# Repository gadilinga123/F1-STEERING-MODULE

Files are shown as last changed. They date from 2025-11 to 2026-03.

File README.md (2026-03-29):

# F1 Steering Wheel Control Module (Ferrari Challenge Project)

## Overview
Designed and implemented an embedded ECU for an F1-style steering wheel, developed under requirements defined by the Ferrari engineering team.  
The system integrates real-time driver inputs, CAN communication, and display feedback.

Complete hardware design files, schematics, and demonstration are included in this repository.

---

## Demo
👉 Full system demonstration (inputs, CAN, display output):  
[▶ Watch Demo Video](./demo.mp4)

---

## System Architecture


The system is built around a centralized control architecture:
- **MCU:** STM32F103 (ARM Cortex-M3)
- **Communication:** CAN (vehicle interface), UART (debug)
- **Display:** SPI-based TFT LCD
- **Inputs:** Digital switches + analog signals (clutch, rotary)
- **Power:** 12V automotive input + USB fallback

---

## My Contributions
- Led end-to-end system development from requirements to validation
- Defined system architecture and hardware partitioning
- Designed complete schematic and 4-layer PCB (Altium Designer)
- Implemented power architecture (DC-DC + LDO design trade-offs)
- Performed hardware bring-up, debugging, and validation using lab equipment
- Resolved critical hardware issue (boot failure due to reset circuit)

---

## System Features
- Multi-input acquisition:
  - Digital inputs (Gear Up/Down + configurable buttons)
  - Analog inputs (clutch control and rotary selector)
- CAN bus communication:
  - Reception of vehicle data (e.g., temperature signals)
  - Control of LED outputs
- Real-time user interface:
  - TFT display (320×240) with dynamic feedback
- Dual power architecture:
  - 12V automotive supply
  - USB-based supply for controlled debugging

---

## Hardware Design

### PCB Design
- 4-layer stackup: Signal / Ground / Power / Signal
- Controlled impedance routing for CAN and USB
- EMI-aware layout and signal integrity optimization

### Power Architecture
- 12V → 3.3V DC-DC converter (>90% efficiency, <5% ripple)
- LDO regulator for low-noise operation and USB debugging
- Protection features:
  - TVS diode (transient suppression)
  - Reverse polarity protection
  - Input filtering (EMI mitigation)

---

## Firmware
- Developed in C using STM32CubeIDE
- Modular architecture:
  - Input acquisition layer
  - Processing logic
  - Output control (display + LEDs)
- CAN communication handling and debugging
- SPI-based display integration

---

## Validation & Testing
- Hardware bring-up and debugging
- Power integrity verification
- Clock stability validation (external oscillator)
- Functional testing:
  - Inputs (buttons, analog)
  - CAN communication
  - Display output
- System-level validation against requirements

---

## Key Technical Metrics
- Power Conversion Efficiency: >90%
- Output Ripple: <5%
- PCB: 4-layer design
- Supply Inputs: 12V automotive + 5V USB fallback

---

## Challenges & Solutions
- **Thermal constraints (no active cooling):**
  - Used efficient DC-DC + thermal vias and ground planes

- **Manufacturing delays:**
  - Continued development using STM32 Nucleo + HMI module

- **Boot failure issue:**
  - Root cause: incorrect reset switch footprint
  - Fix: hardware rework and validation

- **Cost vs automotive protection:**
  - Replaced surge stopper IC with discrete protection (TVS + diode)

---

## Design Files
- Schematics: `/SCHEMATICS/`
- PCB Layout & Altium Files: root directory
- Gerber Files: `/GERBER/`
- Datasheets: `/DATASHEETS & AN/`

---

## Outcome
- Achieved full compliance with all functional requirements
- Recognized as the **only team project meeting all specifications**

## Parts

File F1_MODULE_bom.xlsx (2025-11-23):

Comment | Description | Designator | Footprint | LibRef | Quantity
CC0402KRX7R7BB104 | CAP CER 0.1UF 16V X7R 0402 | C1, C8, C9, C10, C11, C12, C15, C16, C17, C18, C19, C20 | FP-CC0402-MFG | CMP-03422-000048-1 | 12
TMK105B7104KVHF | 0.1 µF ±10% 25V Condensatori ceramici X7R 0402 (1005 metrico), None | C2, C3, C21, C23, C26 | FP-0402-L_1_0_0_05-W_0_5-MFG | CMP-14477-000162-2 | 5
CC0603KRX5R7BB475 | CAP CER 4.7UF 16V X5R 0603 | C4 | FP-CC0603-DA-MFG | CMP-03422-001236-1 | 1
0603CG300J500NT | C0603 30 pF X8R 30ppm/°C 1.00% 25 V | C5, C6 | FP-C0603C-CF-MFG | CMP-03020-002234-1 | 2
EMK212BB7106KG-T | CAP CER 10UF 16V X7R 0805 | C7, C13, C14 | FP-0805-L_2_0_0_2-W_1_25-MFG | CMP-14477-000192-1 | 3
TMK325B7226KMHP | CAP CER 22UF 25V X7R 1210 | C22, C24 | FP-1210-L_3_2_0_3-W_2_5_0-MFG | CMP-14477-002449-2 | 2
CL21C220JBANNNC | Cap Ceramic 22pF 16V C0G 10% 0805 T/R | C25 | CAP_0805 | CL21C220JBANNNC | 1
RVT1H2R2M0405 | Radial Can - SMD ALUMINUM ELECTROLYTIC CAPACITOR S 50V 2.2muF ±20% 0.157Dia 4.00mm | C31 | CAP_EEE_B_PAN | RVT1H2R2M0405 | 1
CC0805KKX7R9BB394 | CAP 390nF 50V ±10% 0805 (2012 Metric) Thickness 1.1mm SMD | C32 | CAPC0805(2012)110_N | CMP-1036-04624-1 | 1
C2012X7S1A156MT000E | Multilayer Ceramic Capacitors 15μF ±20% 25V X5R SMD 0805 | C33 | FP-C2012-125-0_2-MFG | CMP-08246-004727-1 | 1
150060VS75000 | WURTH ELEKTRONIK - 150060VS75000 - LED, Green, SMD, 0603, 30 mA, 2 V, 570 nm | D1 | WL-SMCW_0603_150060xx75000 | CMP-1426-00006-7 | 1
150080RS75000 | LED Uni-Color Red 630nm 2-Pin Chip 0805(2012Metric) T/R | D2 | WL-SMCW_0805_150080xx75000 | CMP-1426-00011-3 | 1
ESD5Z5.0T1G | Transient Voltage Suppressor, Micro-Packaged Diode for ESD Protection, 2-Pin SOD-523, Pb-Free, Tape and Reel | D3 | ONSC-SOD-523-2-502-01_V | CMP-1063-00102-1 | 1
SM712-02HTG | TVS DIODE 12V 31V SOT23-3 | D4 | FP-SM712-MFG | CMP-2000-07561-2 | 1
CMS06(TE12L,Q,M) | DIODE SCHOTTKY 30V 2A MFLAT | D5 | FP-M-FLAT-MFG | CMP-2000-06115-2 | 1
SMBJ17CA | DO-214AA SMB SMBJ Surface Mount 1 Zener Tvs Diode 18.9V 21.7A 600W -55C~150C TJ | D6 | SMBJSeries_LTF | SMBJ17CA | 1
MINISMDC110F/24-2 | PTC RESET FUSE 24V 1.1A 1812 | F1 | FP-MINISMDC110F-24-2-MFG | CMP-08606-000001-1 | 1
FTSH-103-01-F-DV-TR | CONN HEADER SMD 6POS 1.27MM | J1 | FP-FTSH-103-01-F-DV-TR-MFG | CMP-02766-001757-1 | 1
473460001 | CONN RCPT USB2.0 MICRO B SMD R/A | J2 | FP-473460001-MFG | CMP-2000-05246-2 | 1
HTSW-104-07-G-S | CONN HEADER VERT 4POS 2.54MM | J3 | FP-HTSW-104-07-G-S-MFG | CMP-02766-001776-1 | 1
22-28-4121 | KK 254 Breakaway Header, Vertical, 12 Circuits, Tin (Sn) Plating, Mating Pin Length 8.13mm | J4, J6 | 12 POS_2.54MM_MOLEX | 22-28-4121 | 2
1729144 | Block, Terminal; 13.5 A; 250 V; 5.08 mm; 26 to 16 AWG; 4; Screw; Solder; 4 kV | J5 | PHOENIX_1729144 | 1729144 | 1
61300311121 | CONN HEADER VERT 3POS 2.54MM | J7, J8, J9 | 61300311121 | CMP-1502-01062-3 | 3
MDMK2020T1R0MMV | Inductor Power Shielded Wirewound 1uH 20% 1MHz Metal 1.9A 0.064Ohm DCR Automotive T/R | L1 | IND_MDMK2020T1R0MM_TAY | MDMK2020T1R0MMV | 1
SWPA4020S8R2MT | General Purpose Inductor, 8.2uH, 20%, 1 Element, Ferrite-Core, SMD, 1212 | L2 | IND_SWPA4020S8R2MT | SWPA4020S8R2MT | 1
DFE201210U-R33M=P2 | FIXED IND .33UH 3.4A 31MOHM | L3 | FP-DFE201210U-MFG | CMP-06042-016608-1 | 1
SI1013R | MOSFET P-CH 20V 350MA SC75A | Q1 | FP-C15-1445-MFG | CMP-02550-000328-1 | 1
RC0402JR-0710KL | RES 10K OHM 5% 1/16W 0402 | R1, R4, R11, R15 | FP-RC0402-0_4-MFG | CMP-2002-07915-3 | 4
0402WGF1000TCE | RES SMD 1.2K OHM 1% 1/10W 0402 | R2, R3 | FP-MCS0402-MFG | CMP-02407-010762-1 | 2
ERJ2GE0R00X | Chip Resistor, 0 Ohm, 0.1 W, -55 to 155 degC, 0402 (1005 Metric), RoHS, Tape and Reel | R5, R6, R21, R22, R37 | RESC1005X40X25LL05T05 | CMP-2000-07451-1 | 5
AECR0402F20R0K9 | RES SMD 20 OHM 1% 1/16W 0402 | R7, R8, R10, R23 | FP-RT0402-MFG | CMP-2002-02569-2 | 4
CRCW0402390RFKED | RES Thick Film, 390Ω, 1%, 0.063W, 100ppm/°C, 0402 | R9 | FP-CRCW0402-e3-MFG | CMP-1011-00463-3 | 1
ERA2AEB152X | RES SMD 1.5K OHM 0.1% 1/16W 0402 | R12 | RESC1005X40X25LL10T10 | CMP-2002-05878-1 | 1
1206W4F120LT5E | 0.12Ω ±1% 0.25W 1206 Thick Film Chip Resistor AEC-Q200 compliant | R13 | FP-RMCF1206-MFG | CMP-26527-005834-1 | 1
TNPW040233K0BEED | RES SMD 33K OHM 0.1% 1/16W 0402 | R14 | FP-ERA2A-MFG | CMP-2002-05885-2 | 1
AC0402FR-0782KL | CRGCQ0402 82KΩ 1% ±100ppm/°C 50V | R16 | FP-CRGCQ0402-IPC_C | CMP-03211-009791-1 | 1
ERJ-2GEJ161X |  | R17 | RESC1005X40X25NL05T05 | CMP-2002-00462-1 | 1
RC0402JR-074K7L | 4.7 kOhms ±5% 0.063W, 1/16W Chip Resistor 0402 (1005 Metric) Moisture Resistant Thick Film | R18, R20 | FP-RC0402-0_4-MFG | CMP-2002-08011-2 | 2
RC0402FR-07100KL | 100 kOhms ±1% 0.063W, 1/16W Chip Resistor 0402 (1005 Metric) Moisture Resistant Thick Film | R24, R26 | RESC1005X40X25NL05T10 | CMP-2002-07343-1 | 2
AF0402JR-0720KL | Anti-Sulfurated Chip Resistors Automotive Grade 20kΩ 5% 100ppm/°C 0402 | R25 | FP-AF0402-MFG | CMP-03412-045777-1 | 1
0402WGF4022TCE | Anti-Sulfurated Chip Resistors Automotive Grade 40.2kΩ 1% 100ppm/°C 0402 | R27 | FP-AF0402-MFG | CMP-03412-045117-1 | 1
ARG03BTC6341 | RES SMD 100 OHM 1% 1/8W 0603 | R28 | FP-MCT0603-MFG | CMP-02407-002952-1 | 1
CRM2512-JW-3R3ELF | Res Thick Film 2512 3.3 Ohm 5% 2W ±200ppm/C Pad SMD T/R | R38 | RESC6331X80N | CRM2512-JW-3R3ELF | 1
1977223-4 | SWITCH TACTILE SPST-NO 0.05A 12V | SW6 | FP-1977223-4-MFG | CMP-03407-000020-1 | 1
STM32F103CBT6TR | ARM® Cortex®-M3 STM32F1 Microcontroller IC 32-Bit 72MHz 128KB (128K x 8) FLASH | U1 | FP-LQFP48-5B-MFG | CMP-0237-00247-4 | 1
MP2313GJ-P | Switching Voltage Regulators High Effic 1A,24V, 2MHz Syn StepDw Conv | U2 | TSOT23-8_MP2313_MNP | MP2313GJ-P | 1
SN65HVD232QDRQ1 | Texas Instruments - SN65HVD232QDRQ1 - Can Bus, Transceiver, Can, 1, 1, 3 V, 3.6 V, SOIC | U3 | CAN IC | SN65HVD232QDRQ1 | 1
TL1963A-33DCYR | Single Output Low Noise LDO, 1.5 A, Fixed 3.3 V Output, 2.1 to 20 V Input, 4-pin SOT-223 (DCY), -40 to 125 degC, Green (RoHS & no Sb/Br) | U4 | DCY0004A_N | CMP-0395-00535-2 | 1
ABM3BAIG-8.000MHZ-1Z-T | CRYSTAL 8.0000MHZ 18PF SMD | Y1 | FP-ABM3BAIG-MFG | CMP-27762-004085-1 | 1

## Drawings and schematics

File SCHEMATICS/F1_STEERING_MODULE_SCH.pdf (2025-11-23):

# F1 STEERING MODULE

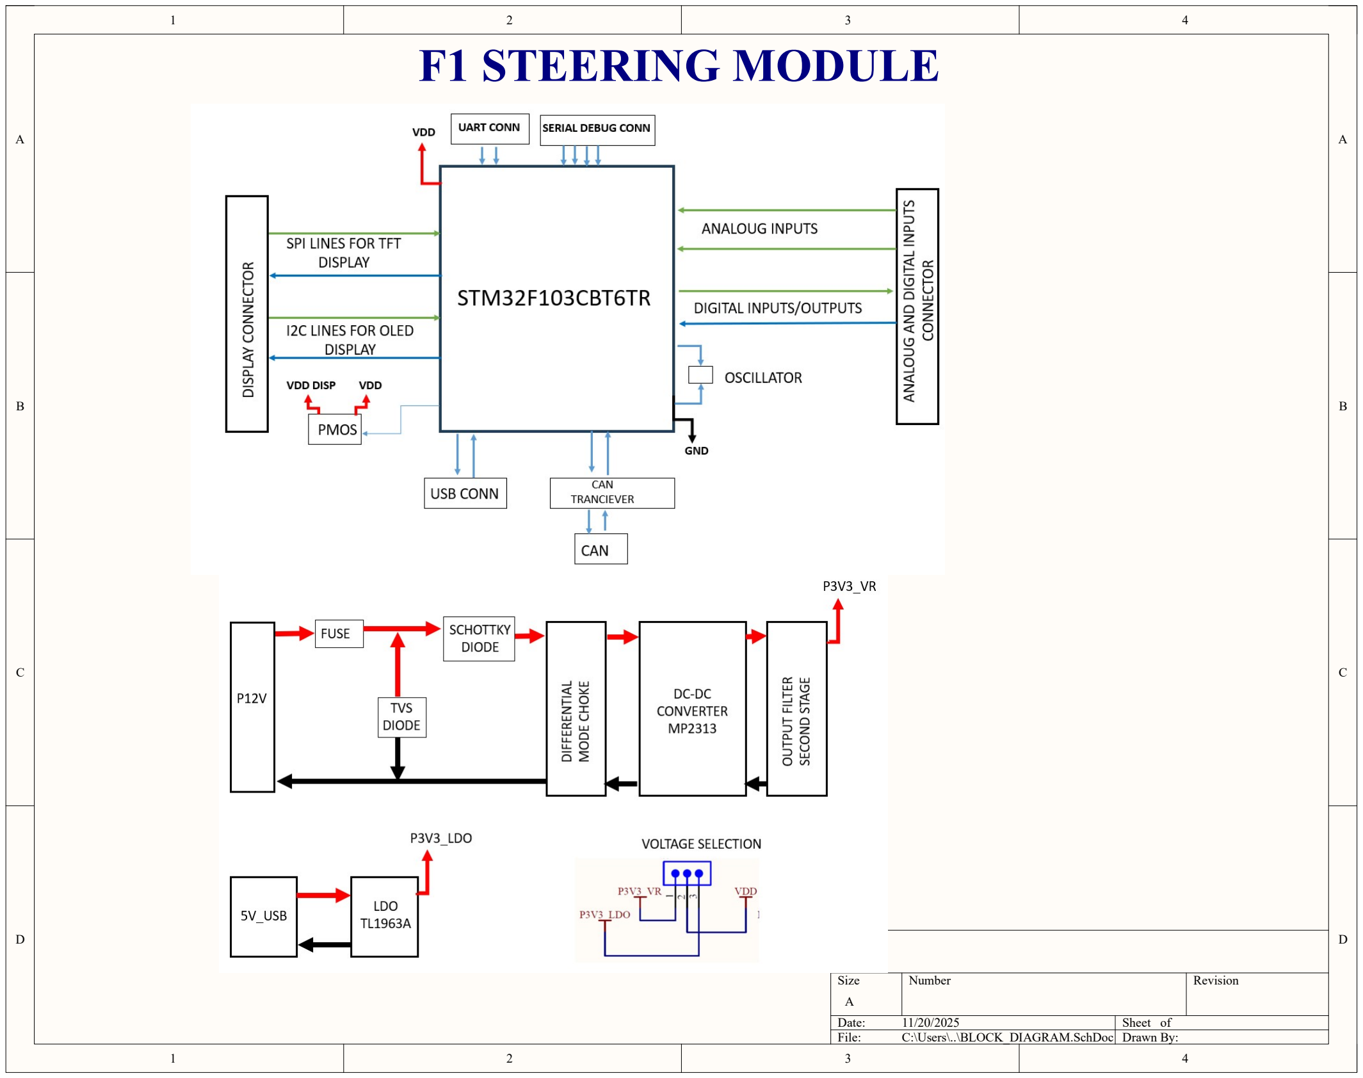
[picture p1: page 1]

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
Title

Size | Number | Revision
A
Date: | 11/20/2025 | Sheet of
File: | C:\Users\..\BLOCK_DIAGRAM.SchDoc | Drawn By:

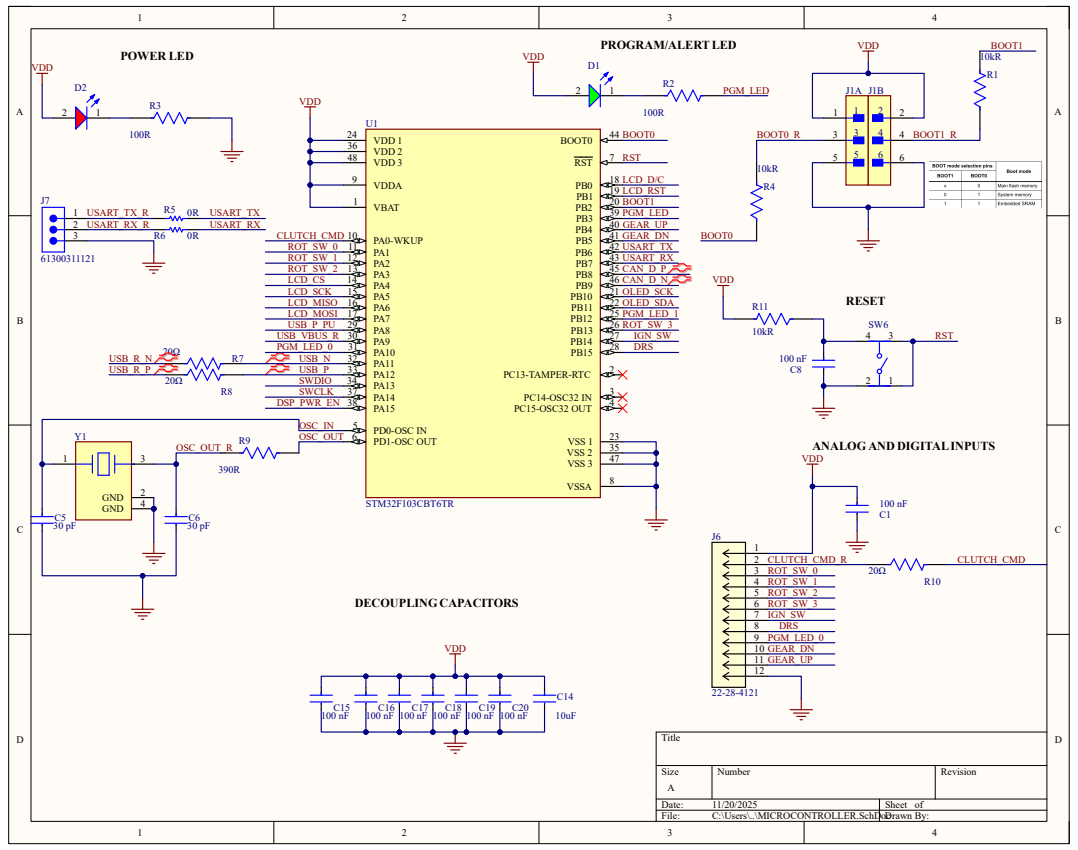
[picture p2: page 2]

ANALOG AND DIGITAL INPUTS
VDD

# 5V_USB 1 2

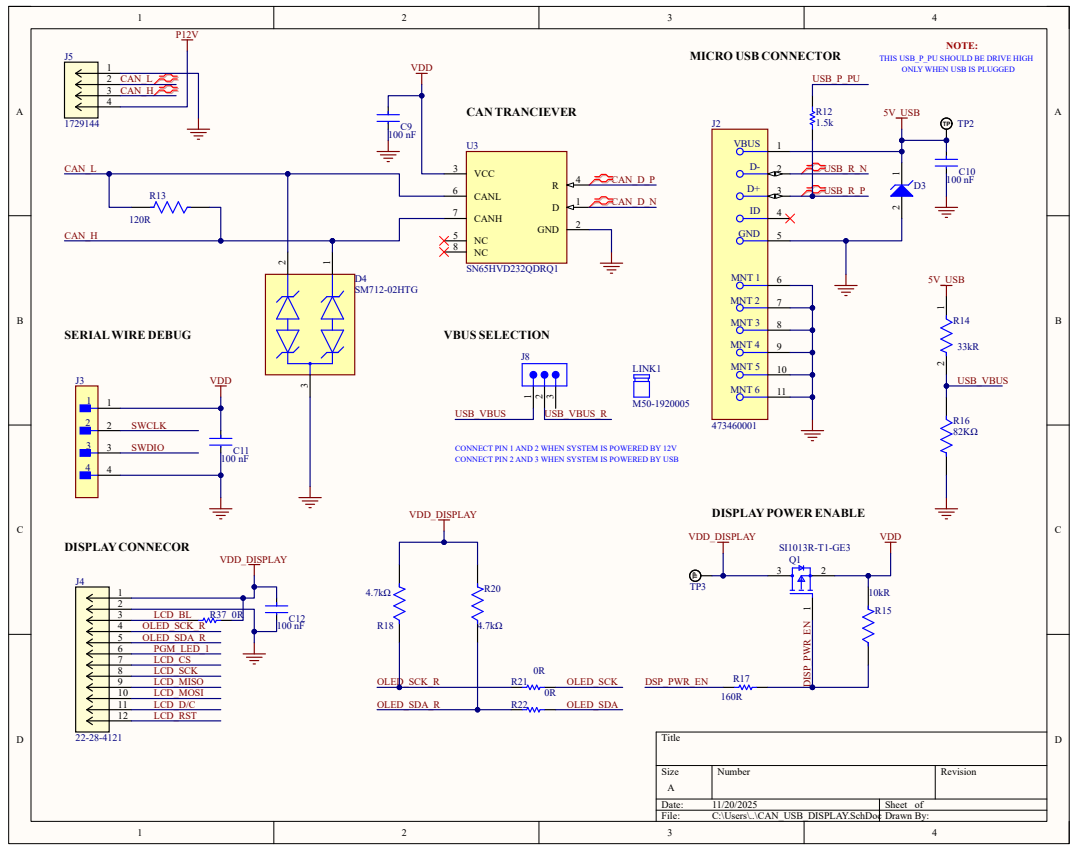
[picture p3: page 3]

THIS USB_P_PU SHOULD BE DRIVE HIGH
ONLY WHEN USB IS PLUGGED

CONNECT PIN 1 AND 2 WHEN SYSTEM IS POWERED BY 12V
CONNECT PIN 2 AND 3 WHEN SYSTEM IS POWERED BY USB

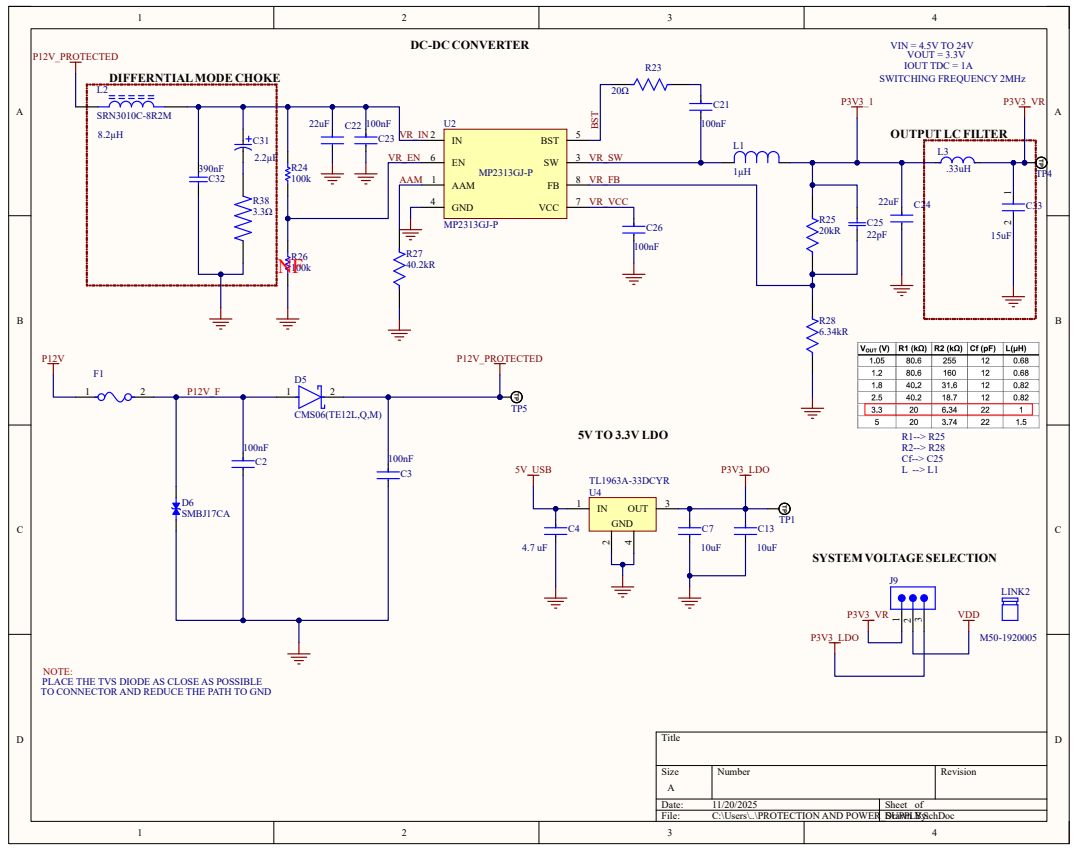
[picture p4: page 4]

NOTE:
PLACE THE TVS DIODE AS CLOSE AS POSSIBLE
TO CONNECTOR AND REDUCE THE PATH TO GND

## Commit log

2025-12-21 Enhance README with project details and features
    Added project description and features for the F1 steering module.
2026-01-06 Revise README for F1-style steering wheel module
    Updated README to enhance clarity and formatting.
2026-03-29 Rename F1 steering module demo.mp4 to demo.mp4
2026-03-29 Revise README for F1 Steering Wheel Control Module
    Updated project title and enhanced overview and contributions sections. Improved clarity in system architecture and features.
